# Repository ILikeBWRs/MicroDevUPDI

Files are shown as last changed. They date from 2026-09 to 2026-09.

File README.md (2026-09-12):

Main project Page: [Here](https://github.com/ILikeBWRs/MicroDev128)

---

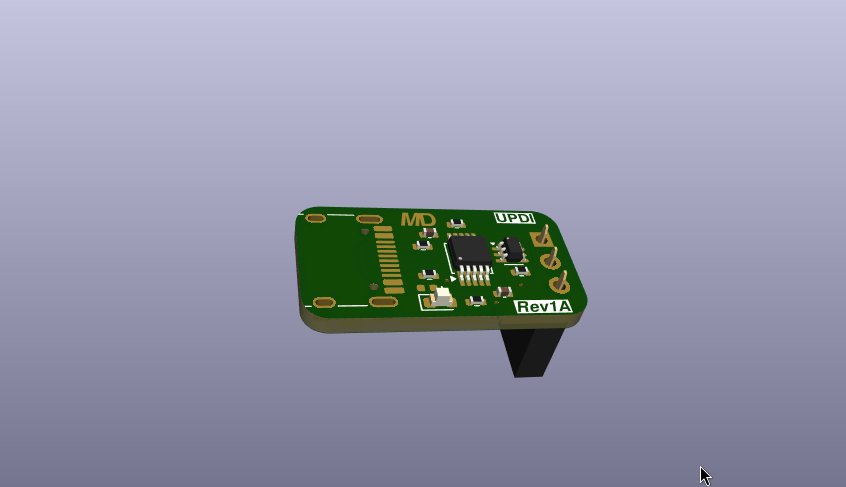
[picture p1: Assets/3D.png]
3D View


# MicroDevUPDI
 A UPDI programmer for the MicroDev128 Series. Compatible with most computers (Linux, Windows, Mac). Based on the CH340E USB to serial chip. This is a simple universal USBtoUDPI converter. 

 Designed on a two layer board feturing reverse polarity protection. Files included for KiCad 10. 

See Document Repo for technical specs: [Here](https://github.com/ILikeBWRs/MicroDev128-Documentation)

Thanks to PCBWay for sponsoring this project!

 ---

 For more information on ordering etc see the main project page. 

 ---

 Revision: *1A*

 Document Version: *1.00*

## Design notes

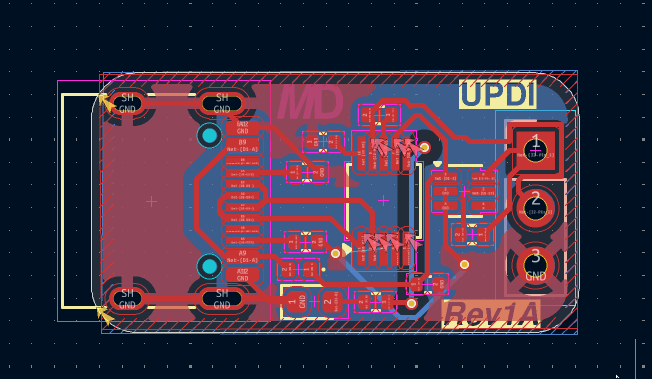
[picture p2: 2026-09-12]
Assets/PCB.png

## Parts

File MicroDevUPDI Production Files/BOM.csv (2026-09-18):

T | Qty | Manufacturer | Mfg Part# | Description/Value | Package | Type | Notes
C1,C2 | 2 | Samsung Electro-Mechanics | CL05B104KO5NNNC | 0.1uF Ceramic X7R Cap | 402 | SMD
D1 | 1 | JCET / Yongyutai / MSKSEMI | MBR0520 | Schottky diode 20V 0.5A | SOD-123 | SMD | Made by many manufacturers – sourcing is not strict
D2 | 1 | Everlight | 19-217/R6C-AL1M2VY/3T | Standard Red SMD Led | 603 | SMD | Any 0603 SMD LED – any colour works
J1 | 1 | Korean Hroparts Elec | TYPE-C-31-M-12 | 16Pin USB-C connector | 16Pin USB-C | SMD + THT
J2 | 1 | DNP | DNP | DNP | DNP | DNP | Do not populate
R1,R2 | 2 | Yageo | RC0402FR-075K1L | 5.1K 1% 1/16W Metal film resistor | 402 | SMD
R3 | 1 | Yageo | RC0402FR-074K7L | 4.7K 1% 1/16W Metal film resistor | 402 | SMD
R4 | 1 | Yageo | RC0402FR-0710KL | 10K, 1% 1/16W Metal film resistor | 402 | SMD
R5 | 1 | Yageo | RC0402FR-07330RL | 330Ohm 1% 1/16W Metal film resistor | 402 | SMD
U1 | 1 | WCH | CH340E | USB serial converter, UART | MSOP-10 | SMD | Must have dot aligned with the arrow, which indicates pin 1
U2 | 1 | Texas Instruments | LM66100DCKR | Ideal Diode With Input Polarity Protection | SC-70-6 | SMD | Must have dot aligned with the arrow, which indicates pin 1

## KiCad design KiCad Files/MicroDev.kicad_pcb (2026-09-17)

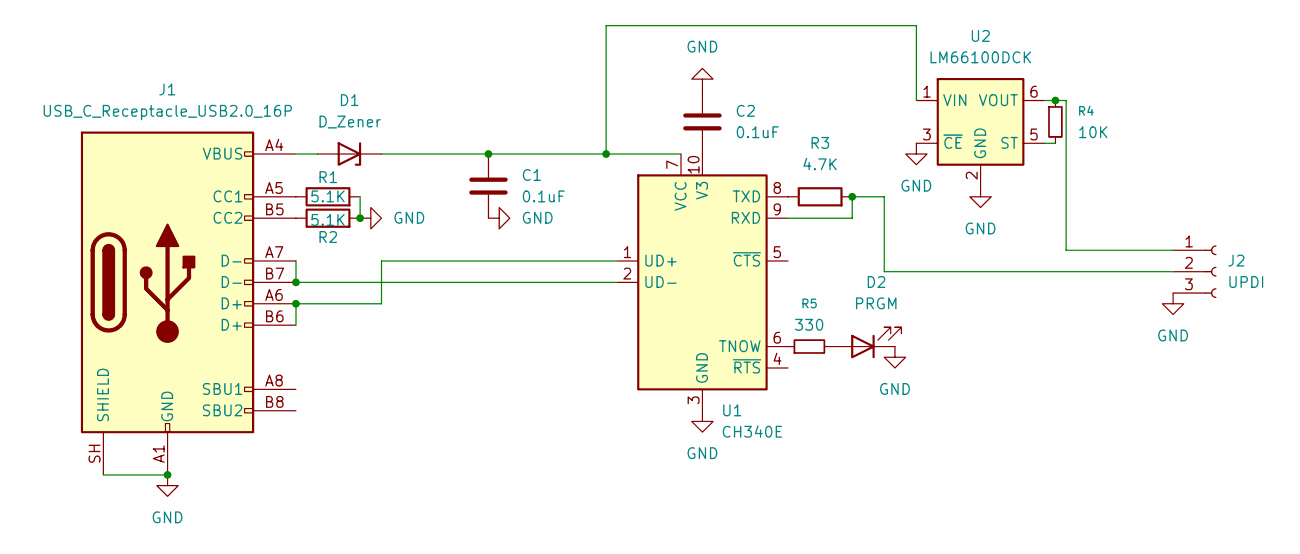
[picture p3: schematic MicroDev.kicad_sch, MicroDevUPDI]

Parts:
C1, C2: 0.1uF; C_0402_1005Metric
D1: D_Zener; D_SOD-123
D2: PRGM; LED_0603_1608Metric
J1: USB_C_Receptacle_USB2.0_16P; USB_C_Receptacle_HRO_TYPE-C-31-M-12
J2: UPDI; PinSocket_1x03_P2.54mm_Vertical
R1, R2: 5.1K; R_0402_1005Metric
R3: 4.7K; R_0402_1005Metric
R4: 10K; R_0402_1005Metric
R5: 330; R_0402_1005Metric
U1: CH340E; MSOP-10_3x3mm_P0.5mm
U2: LM66100DCK; SOT-363_SC-70-6

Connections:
GND: C1.2, C2.1, D2.1 (K), J1.A1 (GND), J1.A12 (GND), J1.B1 (GND), J1.B12 (GND), J1.SH (SHIELD), J2.3, R1.2, R2.2, U1.3 (GND), U2.2 (GND), U2.3 (~CE)
unnamed: D1.2 (A), J1.A4 (VBUS), J1.A9 (VBUS), J1.B4 (VBUS), J1.B9 (VBUS)
unnamed: C1.1, D1.1 (K), U1.7 (VCC), U2.1 (VIN)
unnamed: D2.2 (A), R5.2
unnamed: J1.A5 (CC1), R1.1
unnamed: J1.B5 (CC2), R2.1
unnamed: J2.1, R4.1, U2.6 (VOUT)
unnamed: J2.2, R3.2, U1.9 (RXD)
unnamed: R5.1, U1.6 (TNOW)
unnamed: R3.1, U1.8 (TXD)
unnamed: J1.A6 (D+), J1.B6 (D+), U1.1 (UD+)
unnamed: J1.A7 (D-), J1.B7 (D-), U1.2 (UD-)
unnamed: C2.2, U1.10 (V3)
unnamed: R4.2, U2.5 (ST)

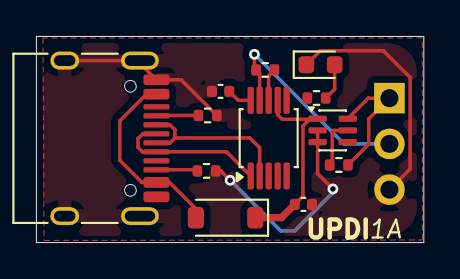
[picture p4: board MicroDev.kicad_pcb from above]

Board: 2 copper layers, 21.5 x 11.5 mm, 13 parts (1 on the bottom side), 14 nets.
